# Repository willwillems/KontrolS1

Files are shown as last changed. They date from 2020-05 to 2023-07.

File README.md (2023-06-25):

S1 Project

The following info is all about the S4 MK1, the MK2 has a different (non-panelized) PCB design and thus doesn't allow for reusing the original PCB's without serious modifications. The MK3 also has a single PCB for the mixer and deck sections.

## Setup
- Use the `Kontrol_S1_LC_OLED` sketch
- Either `#include "unit_d.h"` or `#include "unit_c.h"` based on the unit
- Uncomment `#define SCREEN` if using the OLED module
- Edit the `MIDI_NAME` in the `name.c` file to the desired name (these cannot conflict with other S1 units you're using)
- Flash the firmware

## Led off states
All leds are controlled by a transistor activated by the 595 chip. However not all are connected the same way, sending 6 all-off byte packages (`0b00000000`) will turn some of the LED's on, these specific bits to be set to HIGH instead of LOW in order to be turned off.

```
// LED OFF STATES from least significant bit (so notation is in reverse)
// -- BYTE [0]: 0b01010101 --
// CUE1 green - CUE1 blue - CUE2 green - CUE2 blue - CUE3 green - CUE3 blue - CUE4 green - CUE4 blue 
// -- BYTE [1]: 0b00000000 --
// Sample 1 - Sample 2 - Sample 3 - Sample 4 - SYNC - CUE - PLAY - SHIFT
// -- BYTE [2]: 0b11000000 --
// ON AIR - SAMPLES - DECK A/B - DECK C/D - KEYLOCK - MASTER - TEMPO OFFSET UP - TEMPO OFFSET DOWN
// -- BYTE [3]: 0b00000000 --
// LOOP IN - LOOP OUT - TOGGLE DECK C/D - LOAD - NONE - NONE - NONE -NONE
// -- BYTE [4]: 0b11111111 -- LEFT DIGIT
// UP-MIDDLE - UP-RIGHT - DOT - UP-LEFT - DOWN-LEFT - DOWN-MIDDLE - MIDDLE-MIDDLE - DOWN-RIGHT
// -- BYTE [5]: 0b11111111 -- RIGHT DIGIT
// DM - DL - UL - UM - UR - DR - MM - DOT
```

## Button off states
The first four bits of the last packet are connected to GND trough some 330 R resistors. 

```
// BUTTON OFF STATES
// -- BYTE [0]: 0B00000000 --
// PLAY - CP4 - CUE - CP3 - SYNC - CP2 - SHIFT - CP1
// -- BYTE [1]: 0B00000000 --
// S4 - LOAD - S3 - LOOP OUT - S2 - LOOP IN - DECK C/D
// -- BYTE [2]: 0B00001100 --
// X - X - X - X - ENC-R BUT - ENC-L BUT - OFFSET DOWN - OFFSET UP
```

## Pinout
This is the pinout for the DECK A board the DECK B connector is almost identical (but mirrored). The two exceptions are pin 2 and 13, ~~I have no idea what pin 2 is~~ pin 2 is the 165's DS on the DECK B unit. Click [here](https://i.imgur.com/EdCKgI3.jpg) for the DECK B section.

> WARNING: Pinout changed, check below.

pinout
```
// 595’s output enable is connected to GND.
// 165’s CE (chip enable) is connected to GND.
// (13, 14, 15), (16, 17) and (18, 19) are connected together.

1. Q7 (serial out 165)
2. GND (DS from 165's on DECK B)
3. PL (latch pin 165)
4. CP (clock input 165)
5. ENC4-R (330 R)
6. ENC5-L (330 R)
7. ENC4-R (330 R)
8. ENC5-L (330 R)
9. Q7S (serial out 595) (for DECK B this is the serial out of the 4 upper 595's)
10. DS (serial in 595) (for DECK B this is the serial in of the 2 lower 595's)

11. ST_CP (latch pin 595)
12. SH_CP (clock input 595)
13. GND (For DECK B this is the serial in for the 4 upper 595's)
14. GND
15. GND
16. LED V1 (5v but can just be 3.v)
17. LED V1 (5v but can just be 3.v)
18. LED V2 (3.3v)
19. LED V2 (3.3v)
20. VCC

1. GND
2. VCC
3. POT
4. GND
```

## Chip connections

### 74HC595

There are 6 595 chips chained together (the serial out(`Q7S`) for the last 595 is exposed as pin 9 on the connector).

- `ST_CP` and `SH_CP` of every chip are connected to connector pin 11 and 12.
- `MR` is connected to `VCC` on every chip.
- Output enable (`OE`) is connected to `GND` on every chip.

### 74HC165

There are 3 165 chips chained together.

- Clock enable(`CE`) is connect to `GND` on every chip.
- `PL` and `CP` of every chip are connected to connector pin 3 and 4.

## Jog wheels

The rotation of the jogs is measured by two photo-interrupters ([KTIR0611S](http://www.farnell.com/datasheets/2307823.pdf)). The "push down" of the jog is measured by a photo sensor that gets blocked when you push the platter down on it.

### Connections
The 6 pin JST connector is connected to the circuit with the two photo-interrupters. There is also a connection to a third photo-interrupter but they did not end up mounting and integrating this third one into the final product.
```
1. VCC (3.3v)
2. VCC (3.3v) (this "enables" the optical readings?) 
3. GND
4. ENC R
5. ENC L
6. ENC M (not connected or mounted)
```
The 3 color push cable coming out of the jog:
```
BLUE. GND
RED. VCC (3.3V)
WHITE. SIGNAL (analog read: 800~900 off, 1023 on)
-. DUMMY (unused pin on 4-pin JST connector) 
```
> ## Warning
> The jog press is not yet working so the info about it is possibly wrong. The MK1 does seem to use a IR proximity sensor (probably the [HSDL-9100-024](https://docs.broadcom.com/doc/AV02-2259EN) but so far no reliable readings have been produced. The MK2 uses an Ambient Light Sensor with an I2C Interface called the [VNCL4000](https://cdn-shop.adafruit.com/datasheets/vcnl4000.pdf). The current MK1 problems might just be calibration issues but could also be something more serious.

## Observations
- VCC should be 3.3v, not 5v. The 595 works with 5v and you will not fry the LED's but the 165 will not work and you might damage it.
- You can easily run the 165 and 595 chips with hardware SPI.
- The left and right circuit board are not identical at all though the connectors appear to be.

## Custom FX PCB

The custom FX PCB has the same layout on both sides so only one version is required (it has both the L&R mounting holes). The custom FX PCB provides a 165 and 595 interface for the buttons and LED's respectively and a separate connector for the potentiometer signals.

### Pinout

```
1. INH (165-15) [Clock enable]
2. SER (165-10) [Serial data input]
3. QH (595-9) [Serial data output]
4. LATCH 165 (165-1) [Parallel load input]
5. RCK (595-12) [storage register clock input]
6. QH (165-9) [Serial out]
7. SER (595-14)[Serial data input]
8. CLOCK
9. GND
10. VCC

11. VCC
12. GND
13. FX_3
14. FX_2
15. FX_1
16. FX_DW
```

## Parts

These simplified BOM's are for the MK4 releases of the brain and pot boards.

### Brain board

These are the parts needed to populate 1 brain board, to convert one S4 to two S1 units you'd need these parts x2.

| Part | Amount | Value |
| --- | --- | ----- |
| Molex Picoblade (1.25mm) 10-pin | 3 | |
| Molex Picoblade (1.25mm) 8-pin | 1 | |
| Molex Picoblade (1.25mm) 6-pin | 3 | |
| Molex Picoblade (1.25mm) 4-pin | 2 | |
| M3 metal standoffs | 4 | 15mm  |
| M3 metal screws | 8 | 6mm |
| USB-B socket | 1 | |
| Teensy LC | 1 | |
| Capacitor US 1206 | 1 | 100nF |
| Resistor US 1206 (0805 compatible) | 1 | 1M |

The 1M resistor might need a higher value.

### Pot board

These are the parts needed to populate 1 brain board, to convert one S4 to two S1 units you'd need these parts x2. The standoffs needed are already included with the brain BOM.

| Part | Amount | Value |
| --- | --- | ----- |
| Molex Picoblade (1.25mm) 10-pin | 1 | |
| Molex Picoblade (1.25mm) 6-pin | 1 | |
| Resistor US 0805 | 5 | 82 |
| Resistor US 0805 | 8 | 10K |
| 74HC595D | 1 | |
| 74HC165D | 1 | |
| Capacitor US 1206 | 6 | 100nF |

The four capacitors for the potentiometers might need a lower value.

## Custom OLED PCB

Contains adapter from 1.25mm JST to OLED, a step-up to 12V and some passive components the OLED driver needs.

### Pinout

```
1. GND
2. CLOCK
3. GND
4. MOSI
5. SS-SCREEN
6. VCC
7. DC
8. RST
```

# Screen

The screen uses https://github.com/ErikMinekus/traktor-api-client to get data from traktor + a local server to send it to the teensy over serial.

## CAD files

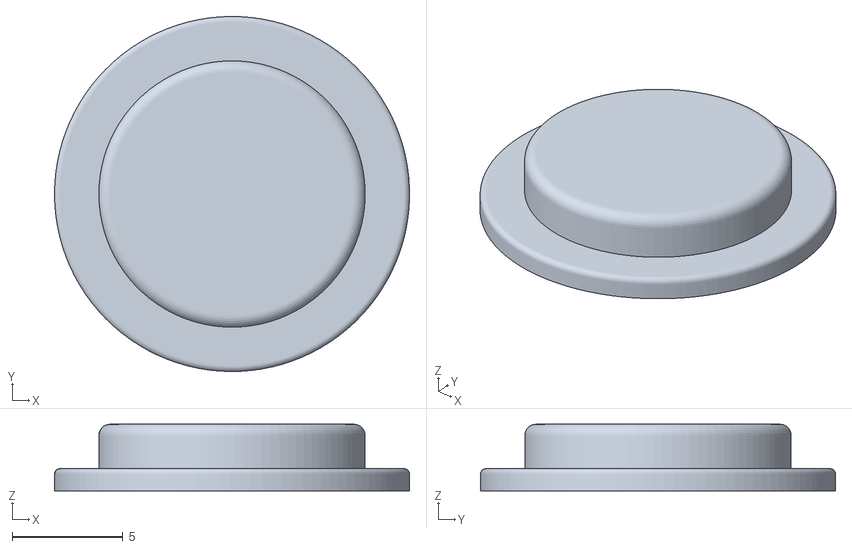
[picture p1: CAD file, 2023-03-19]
3D/s4 front plug.stl
16.0 x 16.0 x 3.00

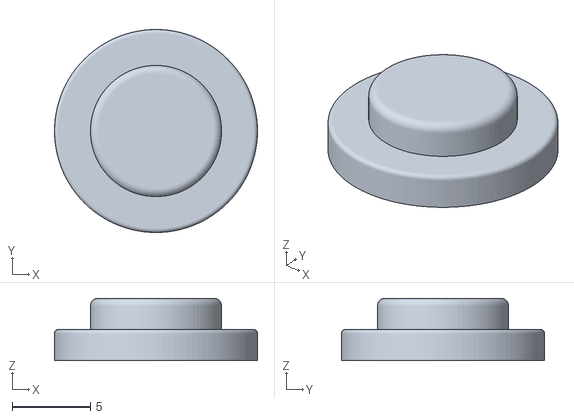
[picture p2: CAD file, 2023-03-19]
3D/s4plugback84-130.stl
13.0 x 13.0 x 4.00

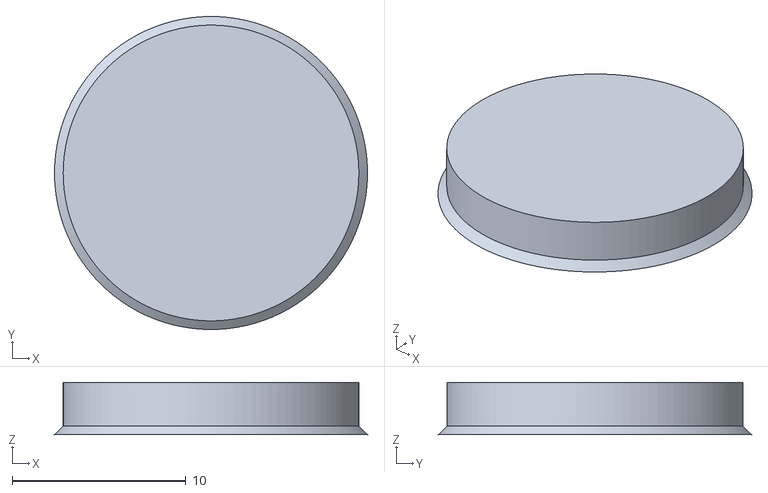
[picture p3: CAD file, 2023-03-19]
3D/midiplug.stl
18.0 x 18.0 x 3.00

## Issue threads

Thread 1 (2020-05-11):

Fader readings have "inertia"

NickolasBoyer, 2020-05-11:
This is when moving the fader up and down quickly:

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

Lower levels are not even reached when moving quickly so it's not simply a delay, feels like a weirdly placed capacitor.

NickolasBoyer, 2020-05-12:
Fixed in 97d0fda pinout was wrong

Closed 2020-05-12.

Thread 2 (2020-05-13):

74HC165 just outputs D7 state on Q7 (all chips)

NickolasBoyer, 2020-05-13:
I might just have fried these chips but not sure about this at all.

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

It does seem like the Q7 only goes high when the latch pin goes low but it subsequently stays high for many SPI cycles until D7 goes low again.

NickolasBoyer, 2020-05-13:
Fixed by 24492eb

Closed 2020-05-13.

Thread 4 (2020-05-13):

Some MIDI note's are inverted

NickolasBoyer, 2020-05-13:
Such as the hotcue buttons, they send a note off on press and a note on on release.

NickolasBoyer, 2020-06-18:
fd906aaf19159a711b77e02d6acf16d90195b7c5 fixes this, typo in default button state, was reading default led state instead of default button state.

Closed 2020-06-18.

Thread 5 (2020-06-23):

Jog touch module does not work yet

NickolasBoyer, 2020-06-23:
Semi-readable values are spitted out by an `analogRead` call but very inconsistently and is influenced by touching the connectors. Mostly `analogRead` just returns: 1023.

NickolasBoyer, 2020-07-02:
From online pictures the proximity sensor seems to be a HSDL-9100. So far some possibel solutions seem to be:

- Using a higher voltage (unlikely)
- Using a pull-down or pull-up resistor with a high value (10K or 100K)

```
----------------------------------------------------

           PhotoR     10K
 +5    o---/\/\/--.--/\/\/---o GND
                  |
 Pin 0 o-----------

----------------------------------------------------
```

NickolasBoyer, 2020-07-11:
This was fixed by using a pull-down resistor, 10K seems to much though.

Closed 2020-07-11.

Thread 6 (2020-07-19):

Add resistors and caps to pots

NickolasBoyer, 2020-07-19:
Like the design of the original S4 PCB, capacitors might stablize potentiometer readigs although  https://github.com/dxinteractive/ResponsiveAnalogRead might already do the job fine.

NickolasBoyer, 2020-11-25:
fixed in 8bfa246

capacitor are optional, resistor was not added

Closed 2020-11-25.

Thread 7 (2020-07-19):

Add smaller current limiting resistors to LED's

NickolasBoyer, 2020-07-19:
Currently the pot board LED's are very dim

NickolasBoyer, 2020-10-20:
Should be fixed in cbd8d652e8d3ef9692d65b48acaec7065aae5a57

Closed 2020-10-20.

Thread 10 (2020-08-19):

Connect both CE's on FX PCB MK3

NickolasBoyer, 2020-08-19:
Currently, only the 165's CE is connected to pin 1 of the FX board. Make it fully SPI compatible (enabling SS) by connecting both the 595's and the 165's.

NickolasBoyer, 2020-09-22:
Not fixed but integrated an alternative using a transistor in fd14755c9442d2429f3247b3a386ff9f93cfd797

Closed 2020-09-22.

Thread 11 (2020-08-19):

Fix dimensions FX MK3 board

NickolasBoyer, 2020-08-19:
The FX board dimensions work but are not perfect, finetune them for the MK3.

NickolasBoyer, 2020-09-22:
Fixed in fd14755c9442d2429f3247b3a386ff9f93cfd797

Closed 2020-09-22.

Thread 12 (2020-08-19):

Add screwholes to FX MK3 board to mount Brain MK2

NickolasBoyer, 2020-08-19:

NickolasBoyer, 2020-09-22:
Fixed in fd14755c9442d2429f3247b3a386ff9f93cfd797

Closed 2020-09-22.

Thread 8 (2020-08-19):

Design custom OLED board

NickolasBoyer, 2020-08-19:
For the SH1122 driven 256 x 64 2.08 inch OLED display.

## Wiring

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

## Docs

- [SH1122](https://www.buydisplay.com/download/ic/SH1122.pdf)
- [Screen module](https://www.buydisplay.com/download/manual/ER-OLED0208-1_Datasheet.pdf)

NickolasBoyer, 2020-09-03:
Position should be either under the display itself but with a relatively small PCB or tucked against the jog, cannot mount on jog screws, that sections protrudes the PCB.

NickolasBoyer, 2020-10-04:
Deigned a small test board in 640ccb3

NickolasBoyer, 2020-11-28:
OLED board is working perfectly

Closed 2020-11-28.

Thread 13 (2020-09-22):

Mounting holes for PCB stacking do not line up

NickolasBoyer, 2020-09-22:

NickolasBoyer, 2020-10-17:
Also bottom silk is mirrored on brain

NickolasBoyer, 2020-10-20:
Both should be fixed in cbd8d652e8d3ef9692d65b48acaec7065aae5a57

Closed 2020-10-20.

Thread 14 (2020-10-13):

Design mixer brain

NickolasBoyer, 2020-10-13:
The mixer section could also be converted to a stand-alone unit.

It uses [ADS7844](https://www.ti.com/product/ADS7844) chips to ADC the pots/faders and sends the values to the CPU over SPI. [Here](https://github.com/vladkosarev/Arduino.ADS7841/blob/master/ADS7841.ino) is an example Arduino sketch.

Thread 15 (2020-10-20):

Convert Brain and Pot board designs to KiCAD

NickolasBoyer, 2020-10-20:
Both (including the custom library) should be converted to KiCAD. One of the board has issues with wierd tracks (inconsistent track width and wire stubs) due to a previous conversion. This too should be fixed. Library can be moved to it's own GH repo and just be used with existing KiCAD symbols.

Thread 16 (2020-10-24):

LED's don't work on deck C

NickolasBoyer, 2020-10-24:
Depends on the code uploaded but seems almost random.

NickolasBoyer, 2020-10-24:
Getting LED's to respond seems to work reliably by adding a 200 ms delay after pulling the latch pin low. They do not work correctly yet though.

NickolasBoyer, 2020-11-25:
fixed in most recent sketches

NickolasBoyer, 2020-11-28:
fixed in 1302d9a

Closed 2020-11-28.

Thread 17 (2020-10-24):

FX board needs capacitor on jog press read

NickolasBoyer, 2020-10-24:
In order to stabilize the incoming analog readings from the IR sensor.

NickolasBoyer, 2020-11-25:
Fixed in 8bfa246

Closed 2020-11-25.

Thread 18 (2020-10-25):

Debounce inputs

NickolasBoyer, 2020-10-25:
Either through hardware or software, something like https://github.com/dxinteractive/ResponsiveAnalogRead might work for the potentiometers, a better scaling algo would also solve this.

NickolasBoyer, 2020-11-28:
possibly fixed in 1302d9a, new boards might eliminate analog noise as well, else we'll implement software debouncing

Closed 2020-11-28.

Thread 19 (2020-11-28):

Encoder buttons on C are inverted

NickolasBoyer, 2020-11-28:

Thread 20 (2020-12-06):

Port pins silkscreen is on wrong side board

NickolasBoyer, 2020-12-06:
Should be on the bottom, is on top.

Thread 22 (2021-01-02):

PCB error

4dvn, 2021-01-02:
Hello,
the zip files of POT_BOARD_MK3.zip & S1-BRAIN-MK2.zip error you need to check and remove it ^^

NickolasBoyer, 2021-01-02:
Thanks for opening the issue! Could you be a bit more specific? I don't recommend manufacturing anything else than the MK4 PCB's btw.

Closed 2023-03-19.

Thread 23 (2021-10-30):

Newer models have different LED wiring

willwillems, 2021-10-30:
Requiring a different ledmap, difference in the C unit seems major, D unit minor.

willwillems, 2022-10-16:
https://github.com/willwillems/KontrolS1/pull/24

Closed 2023-03-19.

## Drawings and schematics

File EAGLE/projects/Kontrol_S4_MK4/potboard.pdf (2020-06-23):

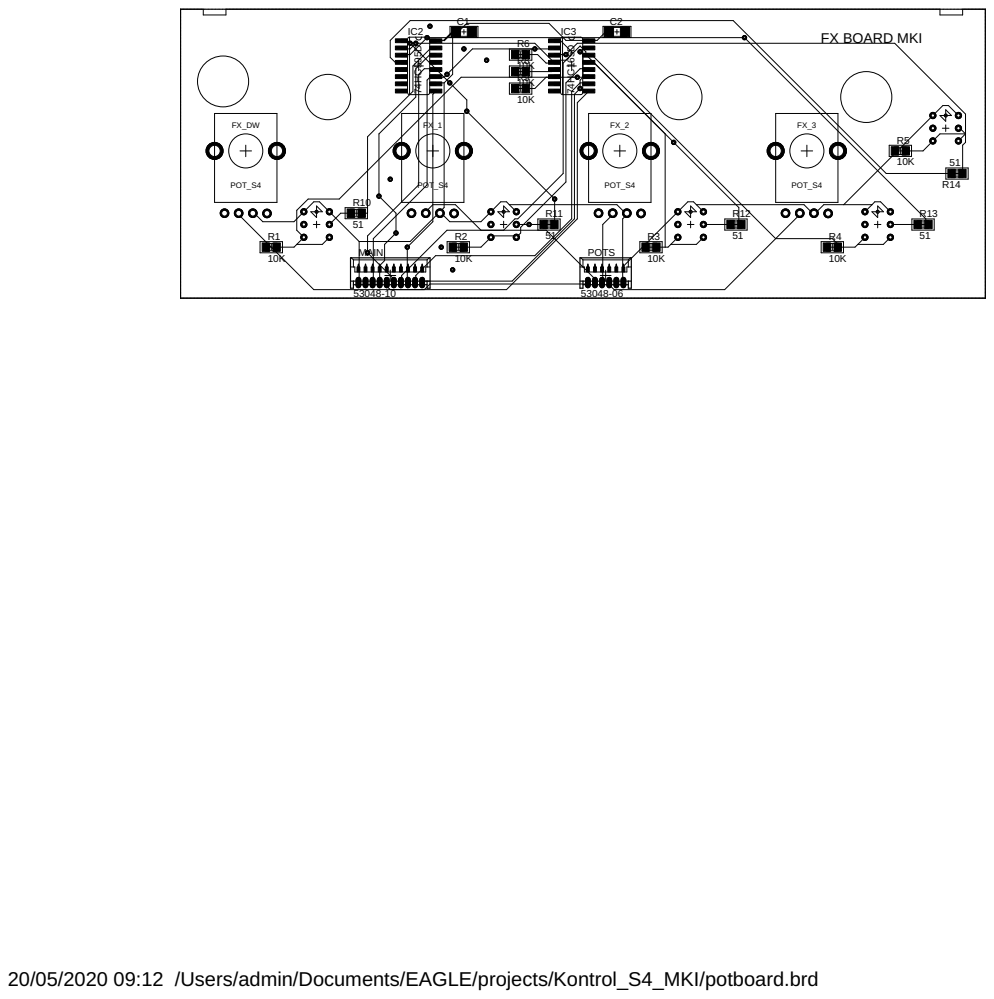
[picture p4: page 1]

20/05/2020 09:12 /Users/admin/Documents/EAGLE/projects/Kontrol_S4_MKI/potboard.brd

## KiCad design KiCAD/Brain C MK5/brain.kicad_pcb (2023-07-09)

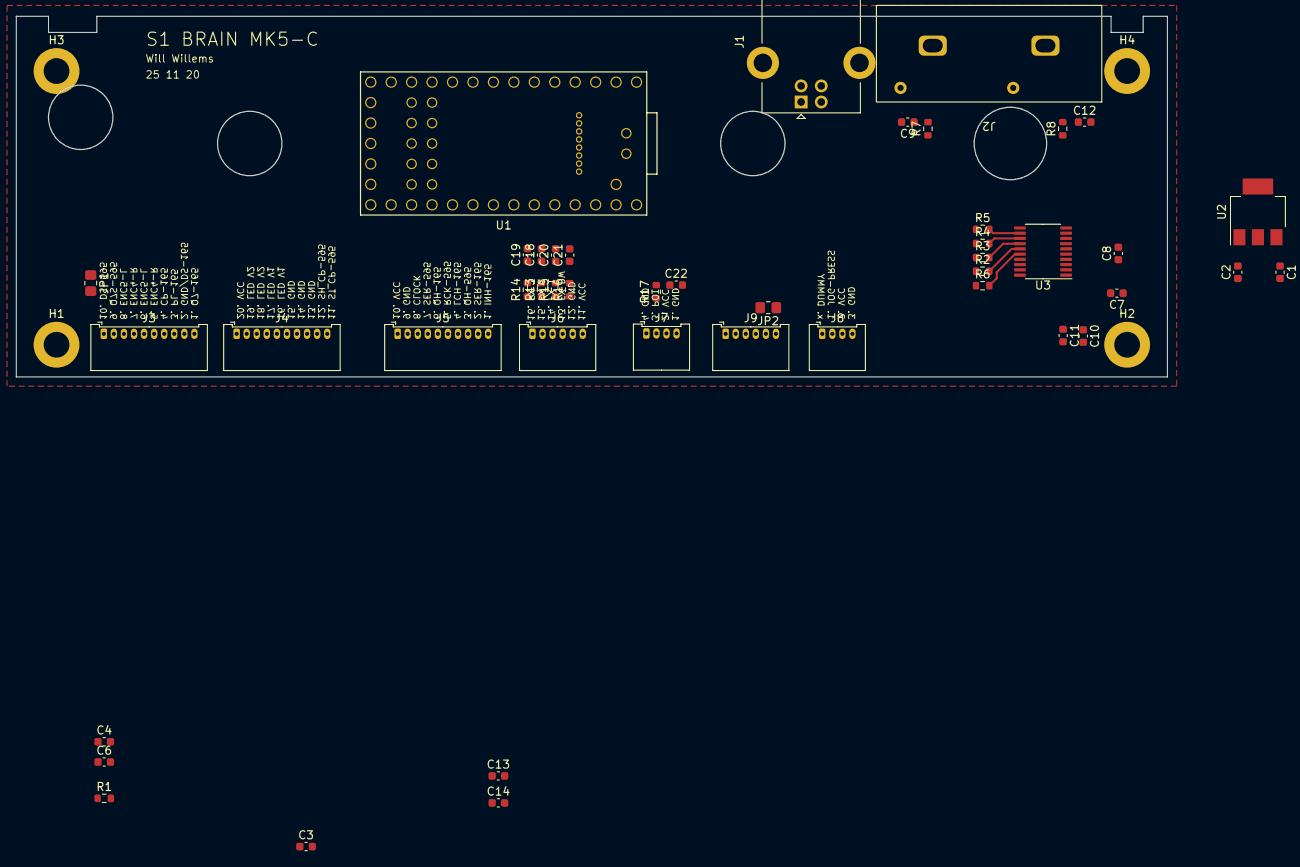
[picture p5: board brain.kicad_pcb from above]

Board: 4 copper layers, 143.0 x 44.8 mm, 49 parts (0 on the bottom side), 49 nets.

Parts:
C1, C3, C4, C6, C10: 100nF; C_0603_1608Metric
C2, C11: 10uF; C_0603_1608Metric
C7, C8: 2.2uF; C_0603_1608Metric
C9, C12: 2.2nF; C_0603_1608Metric
C13, C14: C_Small; C_0603_1608Metric
C18, C19, C20, C21, C22: 1.2uF; C_0603_1608Metric
H1, H2, H3, H4: MountingHole_Pad; MountingHole_3.2mm_M3_ISO7380_Pad
J1: USB_B; USB_B_Lumberg_2411_02_Horizontal
J2: Conn_Coaxial_x2_Isolated; RCA_double
J3, J4, J5: Conn_01x10; Molex_PicoBlade_53048-1010_1x10_P1.25mm_Horizontal
J6, J9: Conn_01x06; Molex_PicoBlade_53048-0610_1x06_P1.25mm_Horizontal
J7, J8: Conn_01x04; Molex_PicoBlade_53048-0410_1x04_P1.25mm_Horizontal
JP1, JP2: Jumper_2_Bridged; R_0805_2012Metric_Pad1.20x1.40mm_HandSolder
R1: 10R; R_0603_1608Metric
R2, R3, R4, R5: 22; R_0603_1608Metric
R6: 0; R_0603_1608Metric
R7, R8: 470; R_0603_1608Metric
R13, R14, R15, R16, R17: 2.2K; R_0603_1608Metric
U1: Teensy4.0; Teensy40_SMT
U2: LD1117S33TR_SOT223; SOT-223-3_TabPin2
U3: PCM5102; TSSOP-20_4.4x6.5mm_P0.65mm

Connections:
+3.3V: C4.1, C6.1, U1.16 (3V3), U1.31 (3V3), U3.1 (CPVDD), U3.20 (DVDD)
+3.3VA: C2.1, C10.1, C11.1, U2.2 (VO), U3.8 (AVDD), U3.17 (XSMT)
+5V: C14.1, R1.1
/165-LATCH: J3.8, J5.7, U1.11 (9_OUT1C)
/595-LATCH: J4.10, J5.6, U1.10 (8_TX2_IN1)
/CE-595-165: J3.9, J5.10, U1.12 (10_CS_MQSR)
/CLOCK: J3.7, J4.9, J5.3, U1.20 (13_SCK_CRX1_LED)
/Connectors/165_BRIDGE: J3.10, J5.9
/Connectors/595_BRIDGE: J3.1, J5.8
/Connectors/595_OUT_MAIN: J3.2, JP1.2 (B)
/DAC (PCM5102)/AUDIO_OUT_L: C12.1, R8.2
/DAC (PCM5102)/AUDIO_OUT_R: C9.1, R7.2
/DAC (PCM5102)/LDO: C3.1, U3.18 (LDOO)
/ENCL1: J3.5, U1.4 (2_OUT2)
/ENCL2: J3.6, U1.5 (3_LRCLK2)
/ENCR1: J3.3, U1.6 (4_BCLK2)
/ENCR2: J3.4, U1.7 (5_IN2)
/FADER_1: J7.2, R17.1
/JOG-MOVE1: J9.2, U1.8 (6_OUT1D)
/JOG-MOVE2: J9.3, U1.9 (7_RX2_OUT1A)
/JOG_PRESS_IR: J8.2, U1.21 (14_A0_TX3_SPDIF_OUT)
/MISO: J5.5, U1.14 (12_MISO_MQSL)
/MOSI: J5.4, U1.13 (11_MOSI_CTX1)
/POT_1: J6.1, R14.1
/POT_2: J6.2, R13.1
/POT_3: J6.3, R15.1
/POT_4: J6.4, R16.1
/USB_D+: J1.3 (D+), U1.54 (D+)
/USB_D-: J1.2 (D-), U1.53 (D-)
GND: C1.2, C2.2, C3.2, C4.2, C6.2, C8.2, C9.2, C10.2, C11.2, C12.2, C13.2, C14.2, C18.2, C19.2, C20.2, C21.2, C22.2, H1.1, H2.1, H3.1, H4.1, J1.4 (GND), J1.5 (Shield), J2.2 (Ext1), J2.4 (Ext2), J4.6, J4.7, J4.8, J5.2, J6.5, J7.1, J7.4, J8.4, J9.4, JP1.1 (A), R6.1, U1.1 (GND), U1.17 (GND), U1.32 (GND), U2.1 (GND), U3.3 (CPGND), U3.9 (AGND), U3.10 (DEMP), U3.11 (FLT), U3.19 (DGND)
unnamed: J9.5, JP2.2 (B)
unnamed: C19.1, R14.2, U1.22 (15_A1_RX3_SPDIF_IN)
unnamed: C18.1, R13.2, U1.23 (16_A2_RX4_SCL1)
unnamed: C20.1, R15.2, U1.24 (17_A3_TX4_SDA1)
unnamed: C21.1, R16.2, U1.25 (18_A4_SDA0)
unnamed: C22.1, R17.2, U1.26 (19_A5_SCL0)
unnamed: C1.1, R1.2, U2.3 (VI)
unnamed: R4.2, U3.13 (BCK)
unnamed: C7.2, U3.4 (CAPM)
unnamed: C7.1, U3.2 (CAPP)
unnamed: R3.2, U3.14 (DIN)
unnamed: R6.2, U3.16 (FMT)
unnamed: R2.2, U3.15 (LRCK)
unnamed: R8.1, U3.6 (OUTL)
unnamed: R7.1, U3.7 (OUTR)
unnamed: R5.2, U3.12 (SCK)
unnamed: C8.1, U3.5 (VNEG)
VBUS: C13.1, J1.1 (VBUS), U1.33 (VIN), U1.34 (VUSB)
VCC: J4.1, J4.2, J4.3, J4.4, J4.5, J5.1, J6.6, J7.3, J8.3, J9.6, JP2.1 (A)

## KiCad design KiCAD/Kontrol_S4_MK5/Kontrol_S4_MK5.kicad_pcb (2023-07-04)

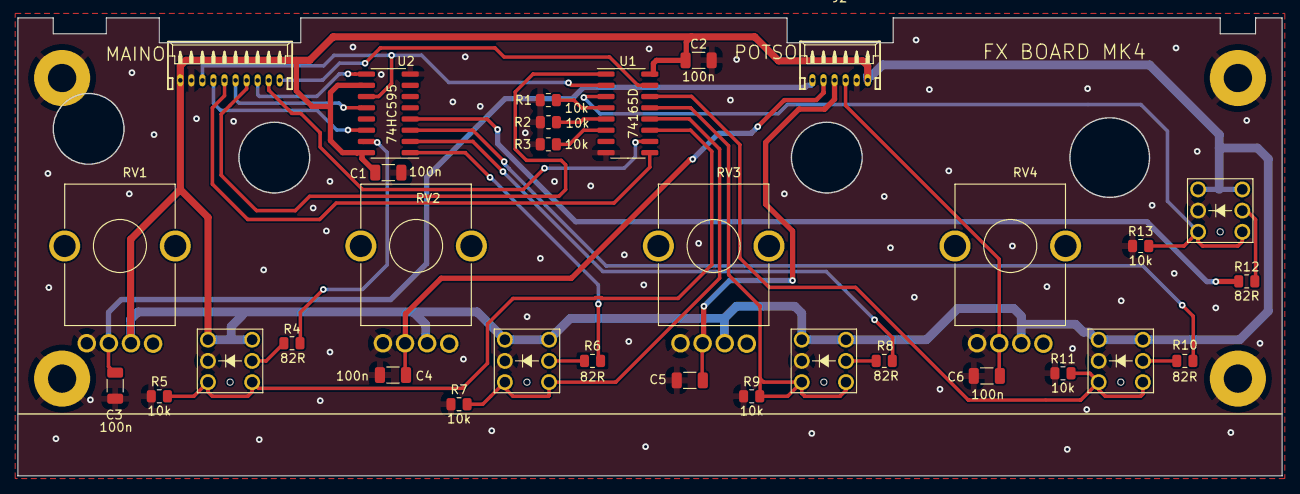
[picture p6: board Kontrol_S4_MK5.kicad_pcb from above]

Board: 2 copper layers, 143.0 x 51.8 mm, 36 parts (0 on the bottom side), 32 nets.

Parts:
C1, C2, C3, C4, C5, C6: 100n; C_1206_3216Metric
H1, H2, H3, H4: STANDOFF_ELECTRICAL; STANDOFF-ELECTRICAL
J1: Conn_01x10; CON_MAINO
J2: Conn_01x06; CON_POTSO
R1, R2, R3, R5, R7, R9, R11, R13: 10k; R_0805_2012Metric
R4, R6, R8, R10, R12: 82R; R_0805_2012Metric
RV1: FX_DWO; Potentiometer_custom
RV2: FX_1; Potentiometer_custom
RV3: FX_2; Potentiometer_custom
RV4: FX_3; Potentiometer_custom
SW1, SW2, SW3, SW4, SW5: Button; BUTTON
U1: 74165D; SOIC-16_3.9x9.9mm_P1.27mm
U2: 74HC595; SOIC-16_3.9x9.9mm_P1.27mm

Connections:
/165_IN: J1.2, U1.10 (SER)
/595_OUT: J1.3, U2.9 (QH')
/A1: C3.1, J2.6, RV1.2
/A2: C4.1, J2.5, RV2.2
/A3: C5.1, J2.4, RV3.2
/A4: C6.1, J2.3, RV4.2
/CE_165: J1.1, U1.15 (CLK_INH)
/CLOCK: J1.8, U1.2 (CLK), U2.11 (SRCLK)
/D1: R5.2, SW1.1, U1.11 (A)
/D2: R7.2, SW2.1, U1.12 (B)
/D3: R9.2, SW3.1, U1.13 (C)
/D4: R11.2, SW4.1, U1.14 (D)
/D5: R13.2, SW5.1, U1.3 (E)
/D6: R1.2, U1.4 (F)
/D7: R2.2, U1.5 (G)
/D8: R3.2, U1.6 (H)
/LATCH_165: J1.4, U1.1 (SH/LD)
/LATCH_595: J1.5, U2.12 (RCLK)
/MISO: J1.6, U1.9 (QH)
/MOSI: J1.7, U2.14 (SER)
GND: C1.2, C2.2, C3.2, C4.2, C5.2, C6.2, H1.P1, H2.P1, H3.P1, H4.P1, J1.9, J2.2, R1.1, R2.1, R3.1, R5.1, R7.1, R9.1, R11.1, R13.1, RV1.3, RV2.3, RV3.3, RV4.3, SW1.LED-, SW2.LED-, SW3.LED-, SW4.LED-, SW5.LED-, U1.8 (GND), U2.8 (GND)
unnamed: R4.1, U2.15 (QA)
unnamed: R4.2, SW1.LED+
unnamed: R6.1, U2.1 (QB)
unnamed: R6.2, SW2.LED+
unnamed: R8.1, U2.2 (QC)
unnamed: R8.2, SW3.LED+
unnamed: R10.1, U2.3 (QD)
unnamed: R10.2, SW4.LED+
unnamed: R12.1, U2.4 (QE)
unnamed: R12.2, SW5.LED+
VCC: C1.1, C2.1, J1.10, J2.1, RV1.1, RV2.1, RV3.1, RV4.1, SW1.2, SW2.2, SW3.2, SW4.2, SW5.2, U1.16 (VCC), U2.10 (~SRCLR), U2.16 (VCC)

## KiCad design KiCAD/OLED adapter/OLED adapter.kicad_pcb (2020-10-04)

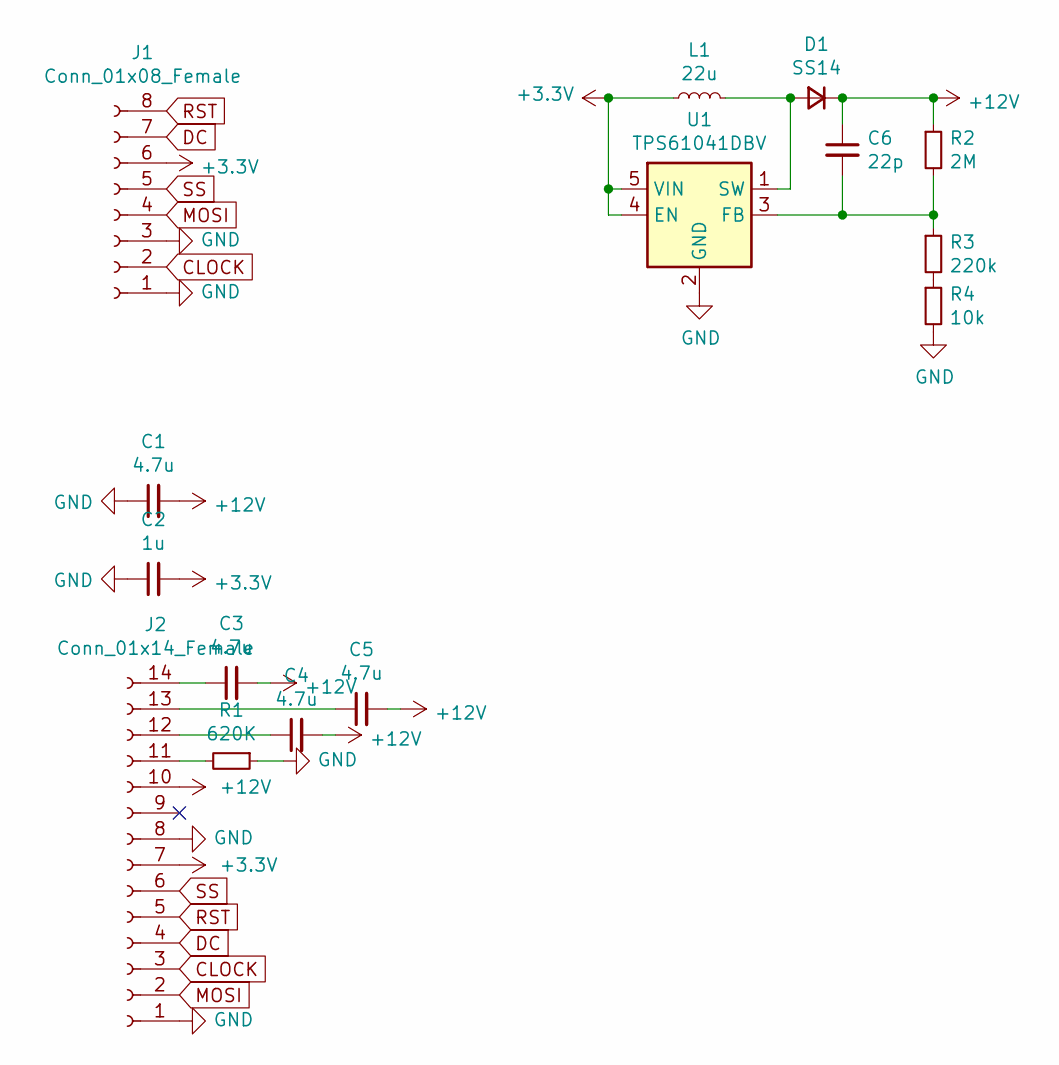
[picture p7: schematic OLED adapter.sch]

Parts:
C1, C3, C4, C5: 4.7u; C_0603_1608Metric_Pad1.05x0.95mm_HandSolder
C2: 1u; C_0603_1608Metric_Pad1.05x0.95mm_HandSolder
C6: 22p; C_0603_1608Metric_Pad1.05x0.95mm_HandSolder
D1: SS14; D_SMA_Handsoldering
J1: Conn_01x08_Female; Hirose_DF13-08P-1.25DS_1x08_P1.25mm_Horizontal
J2: Conn_01x14_Female; TE_1-1734839-4_1x14-1MP_P0.5mm_Horizontal
L1: 22u; L_0805_2012Metric_Pad1.15x1.40mm_HandSolder
R1: 620K; R_0603_1608Metric_Pad1.05x0.95mm_HandSolder
R2: 2M; R_0603_1608Metric_Pad1.05x0.95mm_HandSolder
R3: 220k; R_0603_1608Metric_Pad1.05x0.95mm_HandSolder
R4: 10k; R_0603_1608Metric_Pad1.05x0.95mm_HandSolder
U1: TPS61041DBV; SOT-23-5_HandSoldering

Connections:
+3V3: C2.2, J1.6, J2.7, L1.1, U1.4 (EN), U1.5 (VIN)
+12V: C1.2, C3.2, C4.2, C5.2, C6.1, D1.1 (K), J2.10, R2.1
CLOCK: J1.2, J2.3
DC: J1.7, J2.4
GND: C1.1, C2.1, J1.1, J1.3, J2.1, J2.8, R1.1, R4.2, U1.2 (GND)
MOSI: J1.4, J2.2
unnamed: C3.1, J2.14
unnamed: C4.1, J2.12
unnamed: C5.1, J2.13
unnamed: C6.2, R2.2, R3.1, U1.3 (FB)
unnamed: D1.2 (A), L1.2, U1.1 (SW)
unnamed: J2.11, R1.2
unnamed: R3.2, R4.1
RST: J1.8, J2.5
SS: J1.5, J2.6

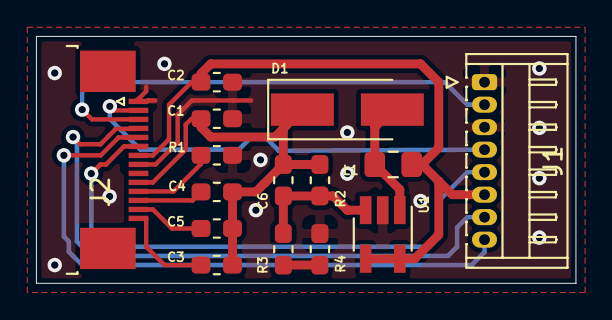
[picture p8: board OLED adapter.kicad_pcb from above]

Board: 2 copper layers, 30.0 x 13.7 mm, 15 parts (0 on the bottom side), 15 nets.

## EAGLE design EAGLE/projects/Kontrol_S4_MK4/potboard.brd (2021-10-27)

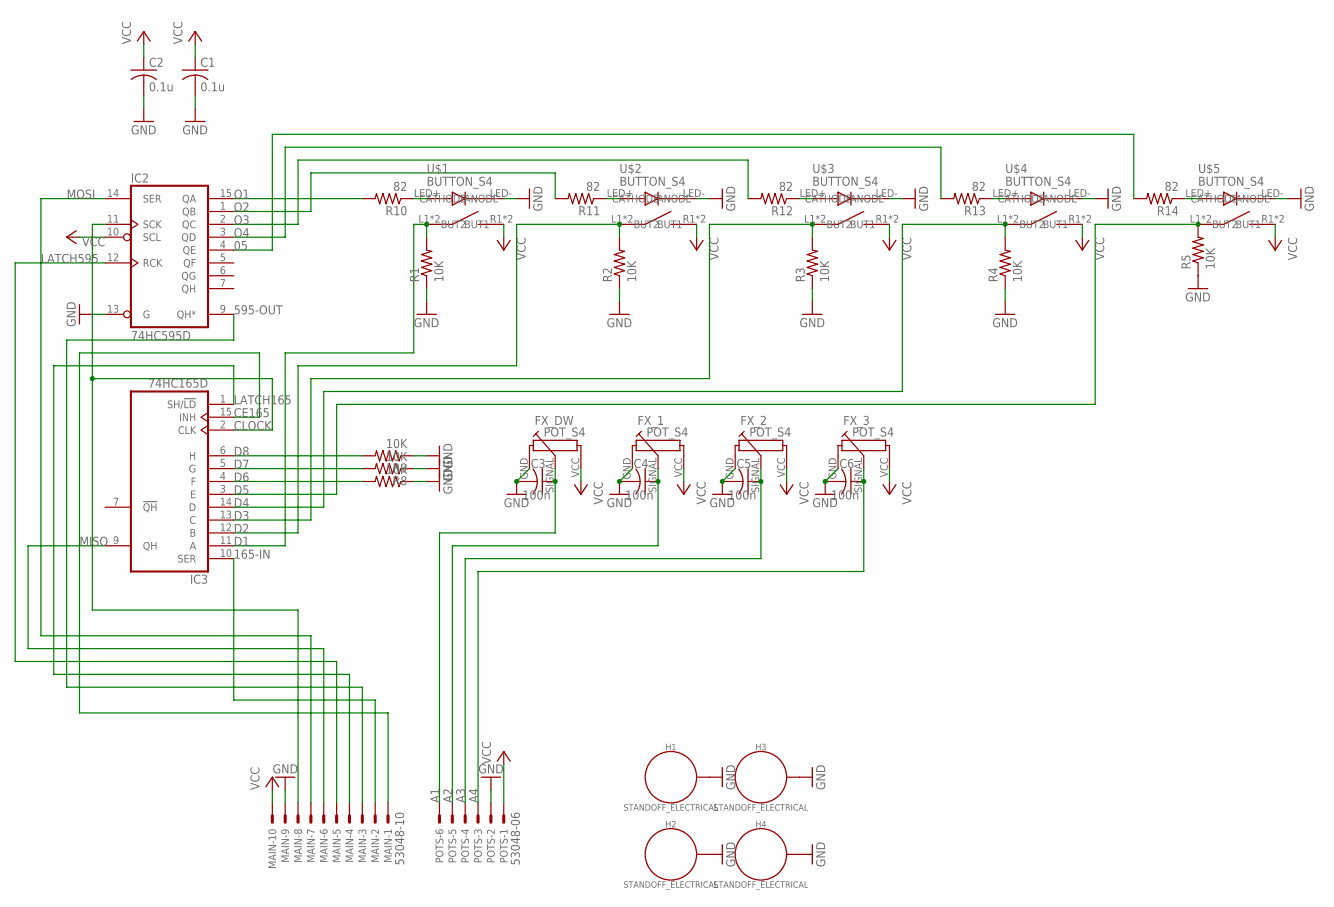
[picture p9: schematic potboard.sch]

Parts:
C1, C2: 0.1u; C1206
C3, C4, C5, C6: 100n; C1206
FX_1, FX_2, FX_3: POT_S4
FX_DW: POT_S4
H1, H2, H3, H4: STANDOFF_ELECTRICAL; STANDOFF-ELECTRICAL
IC2: 74HC595D; SO16
IC3: 74HC165D; SO16
MAIN: 53048-10
POTS: 53048-06
R1, R2, R3, R4, R5, R6, R8, R9: 10K; R0805
R10, R11, R12, R13, R14: 82; R0805
U$1, U$2, U$3, U$4, U$5: BUTTON_S4

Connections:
05: IC2.4 (QE), R14.2
165-IN: IC3.10 (SER), MAIN.2
595-OUT: IC2.9 (QH*), MAIN.3
A1: C3.1, FX_DW.SIGNAL (1S), POTS.6
A2: C4.1, FX_1.SIGNAL (1S), POTS.5
A3: C5.1, FX_2.SIGNAL (1S), POTS.4
A4: C6.1, FX_3.SIGNAL (1S), POTS.3
CE165: IC3.15 (INH), MAIN.1
CLOCK: IC2.11 (SCK), IC3.2 (CLK), MAIN.8
D1: IC3.11 (A), R1.2, U$1.L1 (BUT1), U$1.L2 (BUT1)
D2: IC3.12 (B), R2.2, U$2.L1 (BUT1), U$2.L2 (BUT1)
D3: IC3.13 (C), R3.2, U$3.L1 (BUT1), U$3.L2 (BUT1)
D4: IC3.14 (D), R4.2, U$4.L1 (BUT1), U$4.L2 (BUT1)
D5: IC3.3 (E), R5.2, U$5.L1 (BUT1), U$5.L2 (BUT1)
D6: IC3.4 (F), R6.2
D7: IC3.5 (G), R8.2
D8: IC3.6 (H), R9.2
GND: C1.2, C2.2, C3.2, C4.2, C5.2, C6.2, FX_1.GND (1A), FX_2.GND (1A), FX_3.GND (1A), FX_DW.GND (1A), H1.P1, H2.P1, H3.P1, H4.P1, IC2.8 (GND), IC2.13 (G), IC3.8 (GND), MAIN.9, POTS.2, R1.1, R2.1, R3.1, R4.1, R5.1, R6.1, R8.1, R9.1, U$1.LED- (CATHODE), U$2.LED- (CATHODE), U$3.LED- (CATHODE), U$4.LED- (CATHODE), U$5.LED- (CATHODE)
LATCH165: IC3.1 (SH/!LD), MAIN.4
LATCH595: IC2.12 (RCK), MAIN.5
MISO: IC3.9 (QH), MAIN.6
MOSI: IC2.14 (SER), MAIN.7
unnamed: R10.1, U$1.LED+ (ANODE)
unnamed: R11.1, U$2.LED+ (ANODE)
unnamed: R12.1, U$3.LED+ (ANODE)
unnamed: R13.1, U$4.LED+ (ANODE)
unnamed: R14.1, U$5.LED+ (ANODE)
O1: IC2.15 (QA), R10.2
O2: IC2.1 (QB), R11.2
O3: IC2.2 (QC), R12.2
O4: IC2.3 (QD), R13.2
VCC: C1.1, C2.1, FX_1.VCC (1E), FX_2.VCC (1E), FX_3.VCC (1E), FX_DW.VCC (1E), IC2.10 (SCL), IC2.16 (VCC), IC3.16 (VCC), MAIN.10, POTS.1, U$1.R1 (BUT2), U$1.R2 (BUT2), U$2.R1 (BUT2), U$2.R2 (BUT2), U$3.R1 (BUT2), U$3.R2 (BUT2), U$4.R1 (BUT2), U$4.R2 (BUT2), U$5.R1 (BUT2), U$5.R2 (BUT2)

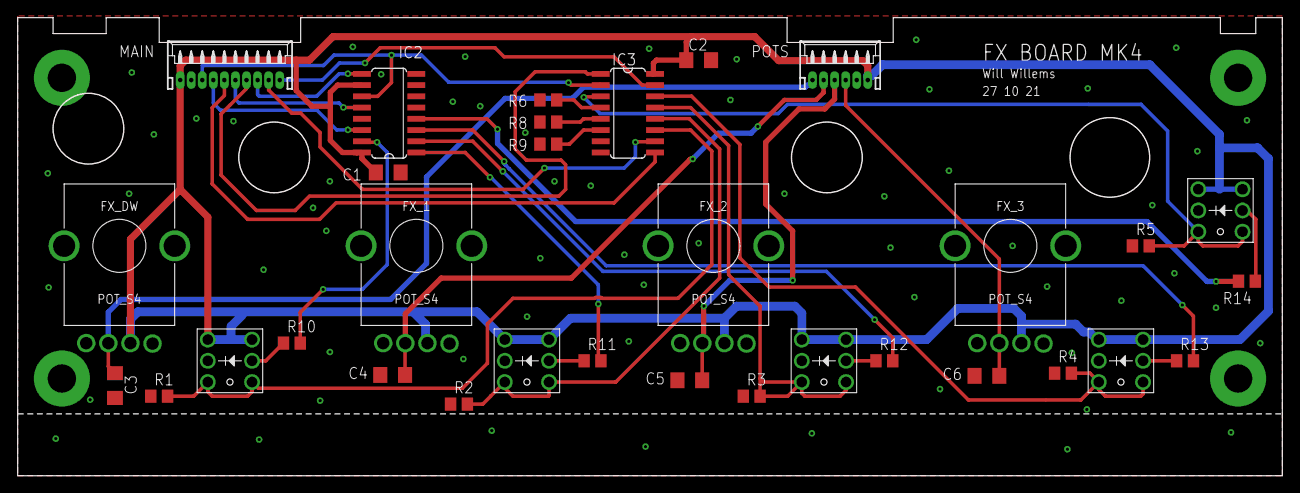
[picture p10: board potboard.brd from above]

Board: 2 copper layers, 143.0 x 51.8 mm, 36 parts (0 on the bottom side), 32 nets.

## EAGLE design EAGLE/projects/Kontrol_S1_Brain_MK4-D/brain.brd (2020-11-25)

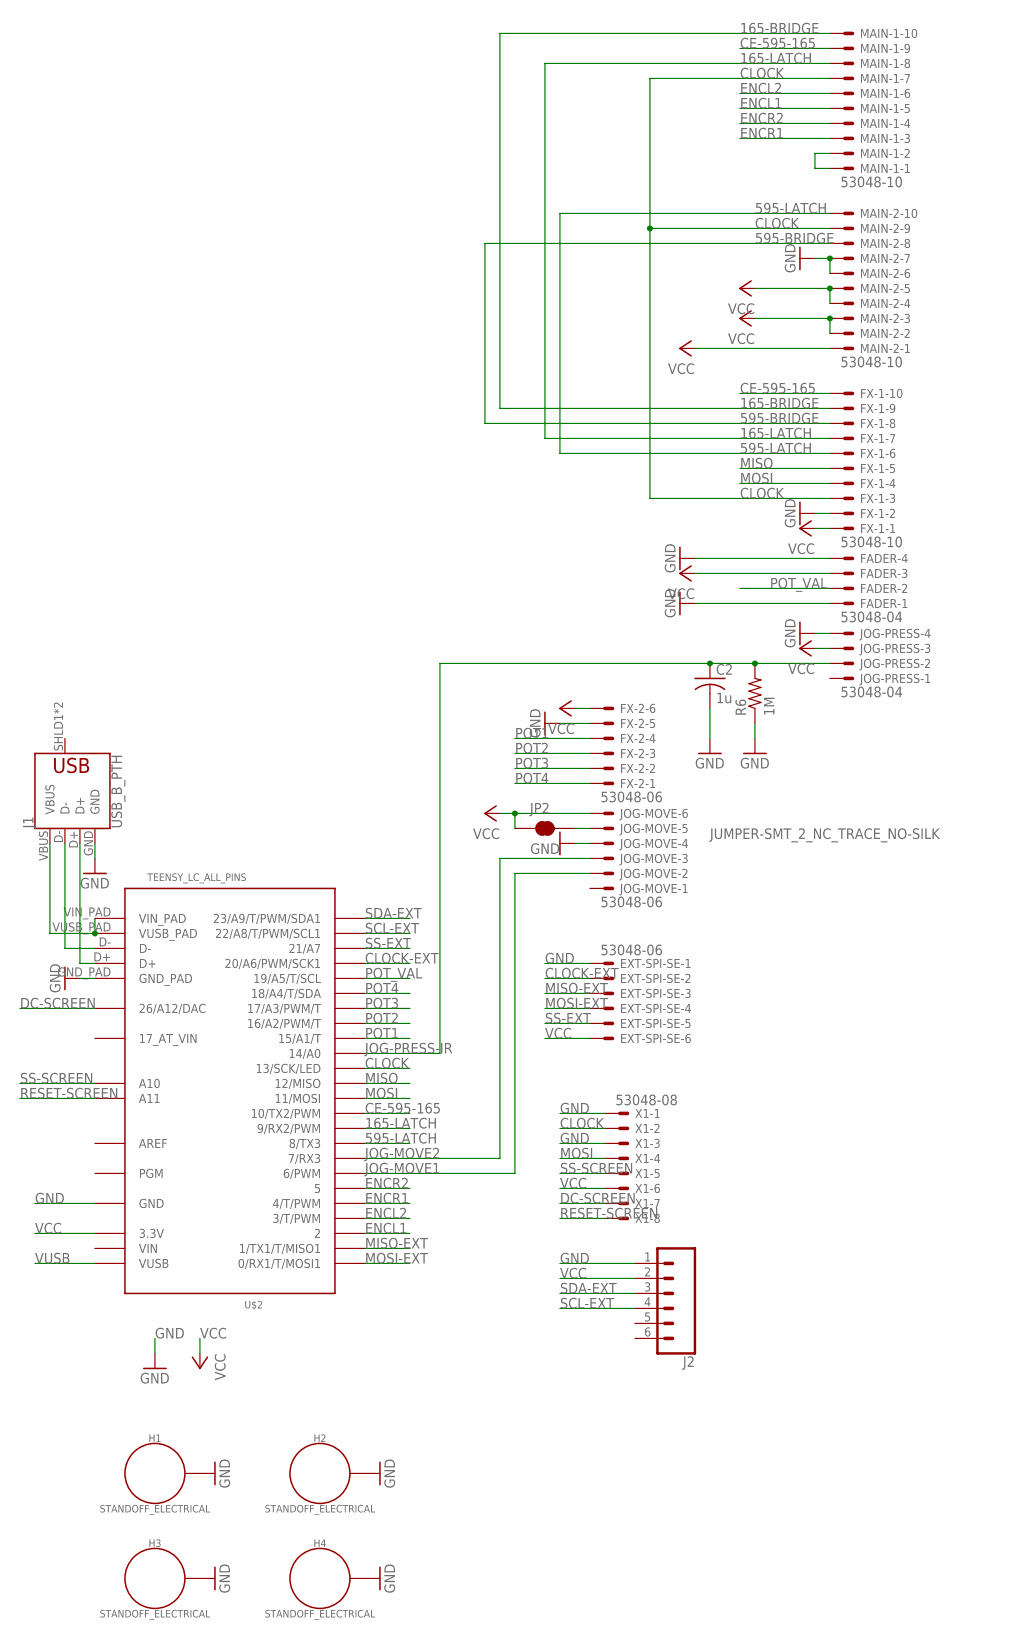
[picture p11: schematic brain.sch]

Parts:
C2: 1u; C1206
EXT-SPI-SE: 53048-06
FADER: 53048-04
FX-1: 53048-10
FX-2: 53048-06
H1, H2, H3, H4: STANDOFF_ELECTRICAL; STANDOFF-ELECTRICAL
J1: USB_B_PTH; USB-B-PTH
J2: CONN_06SILK_FEMALE_PTH; 1X06
JOG-MOVE: 53048-06
JOG-PRESS: 53048-04
JP2: JUMPER-SMT_2_NC_TRACE_NO-SILK; SMT-JUMPER_2_NC_TRACE_NO-SILK
MAIN-1, MAIN-2: 53048-10
R6: 1M; R1206
U$2: TEENSY_LC_ALL_PINS; TEENSY_3.0-3.2&LC_ALL_PINS
X1: 53048-08

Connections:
165-BRIDGE: FX-1.9, MAIN-1.10
165-LATCH: FX-1.7, MAIN-1.8, U$2.9 (9/RX2/PWM)
595-BRIDGE: FX-1.8, MAIN-2.8
595-LATCH: FX-1.6, MAIN-2.10, U$2.8 (8/TX3)
AREF: U$2.AREF
CE-595-165: FX-1.10, MAIN-1.9, U$2.10 (10/TX2/PWM)
CLOCK: FX-1.3, MAIN-1.7, MAIN-2.9, U$2.13 (13/SCK/LED), X1.2
CLOCK-EXT: EXT-SPI-SE.2, U$2.20/A6 (20/A6/PWM/SCK1)
DC-SCREEN: U$2.RESET/DAC (26/A12/DAC), X1.7
ENCL1: MAIN-1.5, U$2.2
ENCL2: MAIN-1.6, U$2.3 (3/T/PWM)
ENCR1: MAIN-1.3, U$2.4 (4/T/PWM)
ENCR2: MAIN-1.4, U$2.5
GND: C2.2, EXT-SPI-SE.1, FADER.1, FADER.4, FX-1.2, FX-2.5, H1.P1, H2.P1, H3.P1, H4.P1, J1.GND, J2.1, JOG-MOVE.4, JOG-PRESS.4, MAIN-2.6, MAIN-2.7, R6.1, U$2.AGND (GND), U$2.GND, U$2.GND1 (GND), U$2.GND_PAD, X1.1, X1.3
JOG-MOVE1: JOG-MOVE.2, U$2.6 (6/PWM)
JOG-MOVE2: JOG-MOVE.3, U$2.7 (7/RX3)
JOG-PRESS-IR: C2.1, JOG-PRESS.2, R6.2, U$2.14/A0
MISO: FX-1.5, U$2.12 (12/MISO)
MISO-EXT: EXT-SPI-SE.3, U$2.1 (1/TX1/T/MISO1)
MOSI: FX-1.4, U$2.11 (11/MOSI), X1.4
MOSI-EXT: EXT-SPI-SE.4, U$2.0 (0/RX1/T/MOSI1)
unnamed: JOG-MOVE.5, JP2.2
unnamed: MAIN-1.1, MAIN-1.2
unnamed: J1.VBUS, U$2.VIN_PAD, U$2.VUSB_PAD
unnamed: J1.D-, U$2.D-
unnamed: J1.D+, U$2.D+
POT1: FX-2.4, U$2.15/A1 (15/A1/T)
POT2: FX-2.3, U$2.16/A2 (16/A2/PWM/T)
POT3: FX-2.2, U$2.17/A3 (17/A3/PWM/T)
POT4: FX-2.1, U$2.18/A4 (18/A4/T/SDA)
POT_VAL: FADER.2, U$2.19/A5 (19/A5/T/SCL)
RESET-SCREEN: U$2.A11, X1.8
SCL-EXT: J2.4, U$2.22/A8 (22/A8/T/PWM/SCL1)
SDA-EXT: J2.3, U$2.23/A9 (23/A9/T/PWM/SDA1)
SS-EXT: EXT-SPI-SE.5, U$2.21/A7
SS-SCREEN: U$2.A10, X1.5
VCC: EXT-SPI-SE.6, FADER.3, FX-1.1, FX-2.6, J2.2, JOG-MOVE.6, JOG-PRESS.3, JP2.1, MAIN-2.1, MAIN-2.2, MAIN-2.3, MAIN-2.4, MAIN-2.5, U$2.3.3V, U$2.3.3V1 (3.3V), X1.6
VIN: U$2.VIN
VUSB: U$2.VUSB

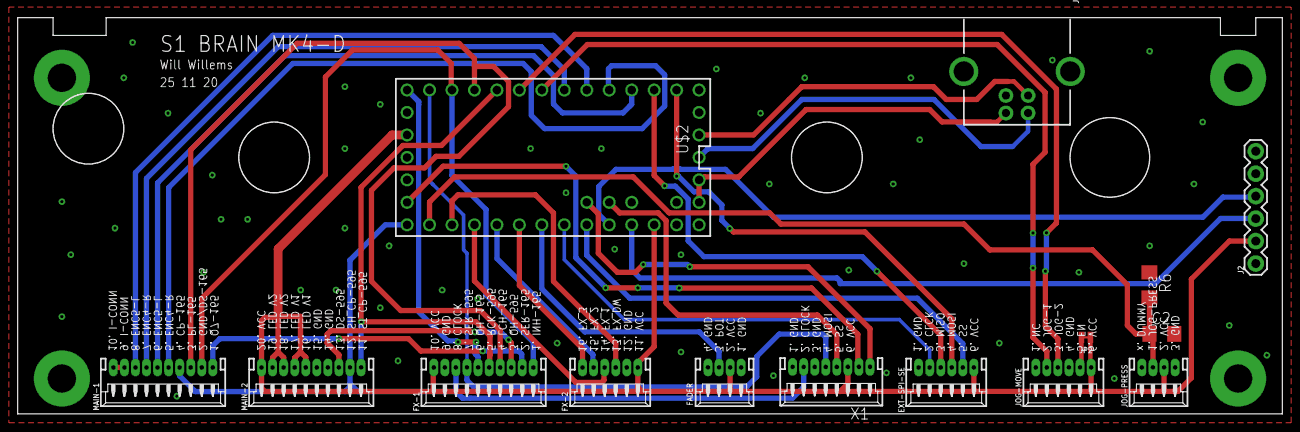
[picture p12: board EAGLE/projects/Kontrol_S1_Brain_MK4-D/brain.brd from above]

Board: 2 copper layers, 143.0 x 44.8 mm, 19 parts (0 on the bottom side), 36 nets.

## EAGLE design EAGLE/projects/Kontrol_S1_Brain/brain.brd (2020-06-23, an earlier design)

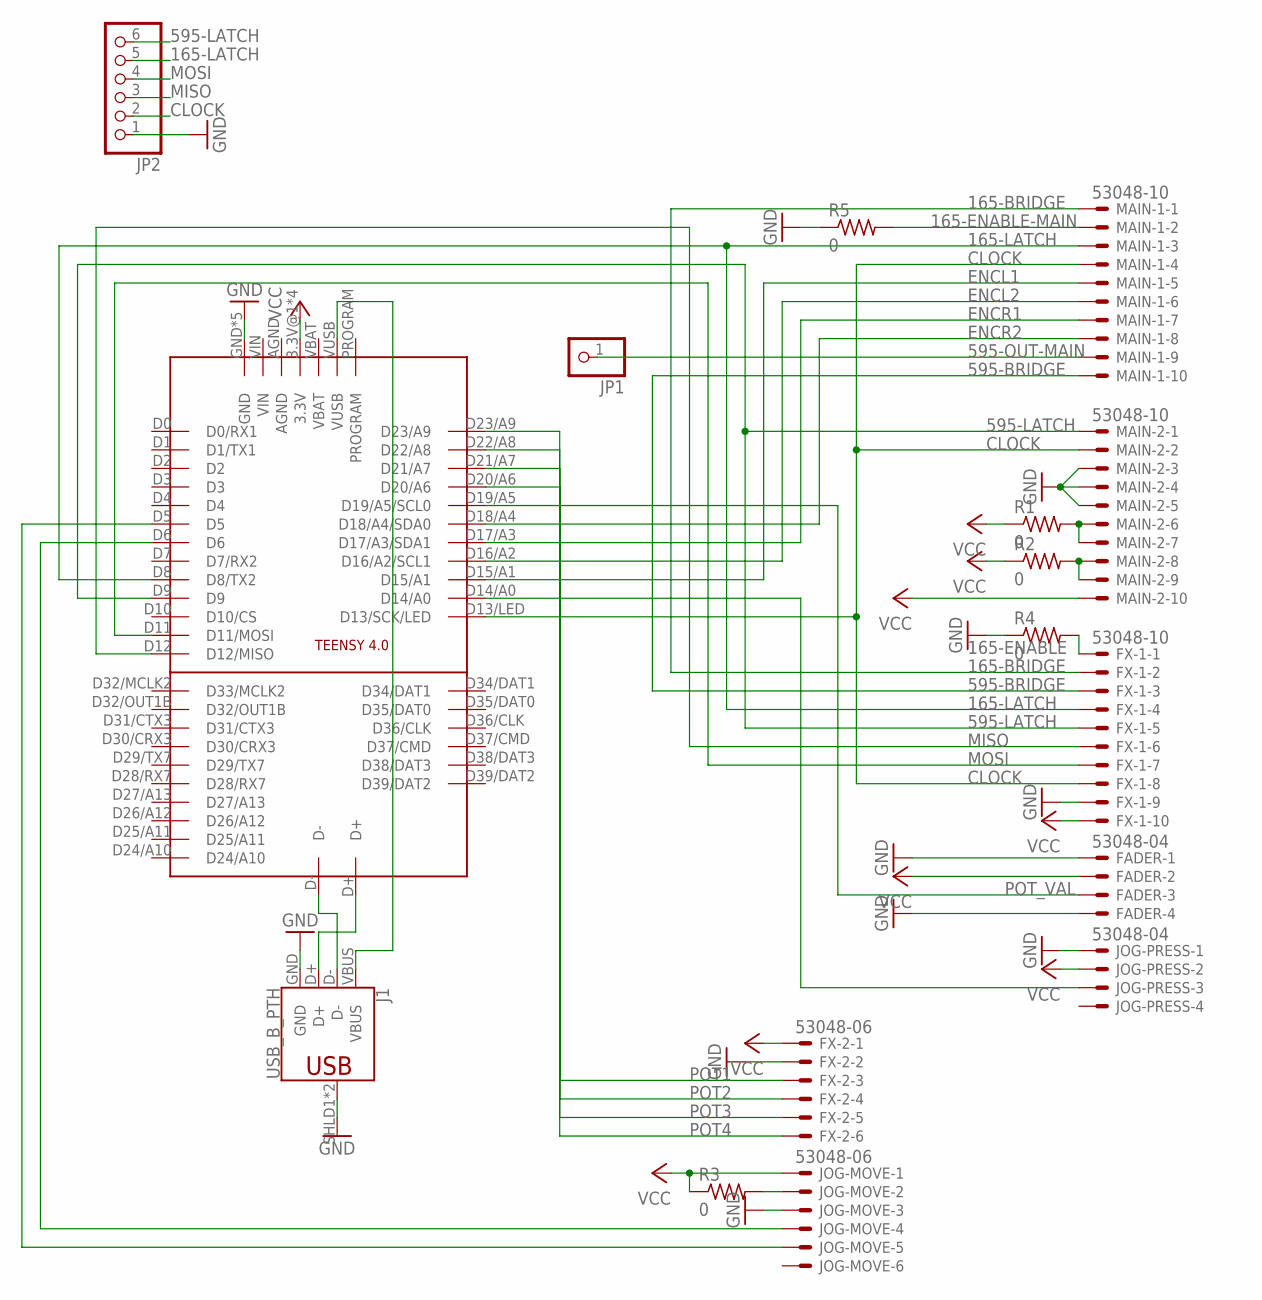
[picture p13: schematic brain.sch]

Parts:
FADER: 53048-04
FX-1: 53048-10
FX-2: 53048-06
J1: USB_B_PTH; USB-B-PTH
JOG-MOVE: 53048-06
JOG-PRESS: 53048-04
JP1: PINHD-1X1; 1X01
JP2: PINHD-1X6; 1X06
MAIN-1, MAIN-2: 53048-10
R1, R2, R3, R4, R5: 0; R1206
U$1: TEENSY-4.0-FULL-BRAKE-PADS

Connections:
165-BRIDGE: FX-1.2, MAIN-1.1
165-ENABLE: FX-1.1, R4.2
165-ENABLE-MAIN: MAIN-1.2, R5.2
165-LATCH: FX-1.4, JP2.5, MAIN-1.3, U$1.D8 (D8/TX2)
595-BRIDGE: FX-1.3, MAIN-1.10
595-LATCH: FX-1.5, JP2.6, MAIN-2.1, U$1.D9
595-OUT-MAIN: JP1.1, MAIN-1.9
CLOCK: FX-1.8, JP2.2, MAIN-1.4, MAIN-2.2, U$1.D13/LED (D13/SCK/LED)
ENCL1: MAIN-1.5, U$1.D15/A1
ENCL2: MAIN-1.6, U$1.D16/A2 (D16/A2/SCL1)
ENCR1: MAIN-1.7, U$1.D17/A3 (D17/A3/SDA1)
ENCR2: MAIN-1.8, U$1.D18/A4 (D18/A4/SDA0)
GND: FADER.1, FADER.4, FX-1.9, FX-2.2, J1.GND, J1.SHLD1 (SHIELD), J1.SHLD2 (SHIELD), JOG-MOVE.3, JOG-PRESS.1, JP2.1, MAIN-2.3, MAIN-2.4, MAIN-2.5, R4.1, R5.1, U$1.GND, U$1.GND@1 (GND), U$1.GND@2 (GND), U$1.P$11 (GND), U$1.P$12 (GND)
MISO: FX-1.6, JP2.3, U$1.D12 (D12/MISO)
MOSI: FX-1.7, JP2.4, U$1.D11 (D11/MOSI)
unnamed: MAIN-2.8, MAIN-2.9, R2.2
unnamed: MAIN-2.6, MAIN-2.7, R1.2
unnamed: JOG-PRESS.3, U$1.D14/A0
unnamed: JOG-MOVE.2, R3.2
unnamed: JOG-MOVE.4, U$1.D6
unnamed: JOG-MOVE.5, U$1.D5
unnamed: J1.D+, U$1.D+
unnamed: J1.D-, U$1.D-
unnamed: J1.VBUS, U$1.VUSB
POT1: FX-2.3, U$1.D20/A6
POT2: FX-2.4, U$1.D21/A7
POT3: FX-2.5, U$1.D22/A8
POT4: FX-2.6, U$1.D23/A9
POT_VAL: FADER.3, U$1.D19/A5 (D19/A5/SCL0)
VCC: FADER.2, FX-1.10, FX-2.1, JOG-MOVE.1, JOG-PRESS.2, MAIN-2.10, R1.1, R2.1, R3.1, U$1.3.3V@1 (3.3V), U$1.3.3V@2 (3.3V), U$1.3V3 (3.3V), U$1.ON/OFF (3.3V)

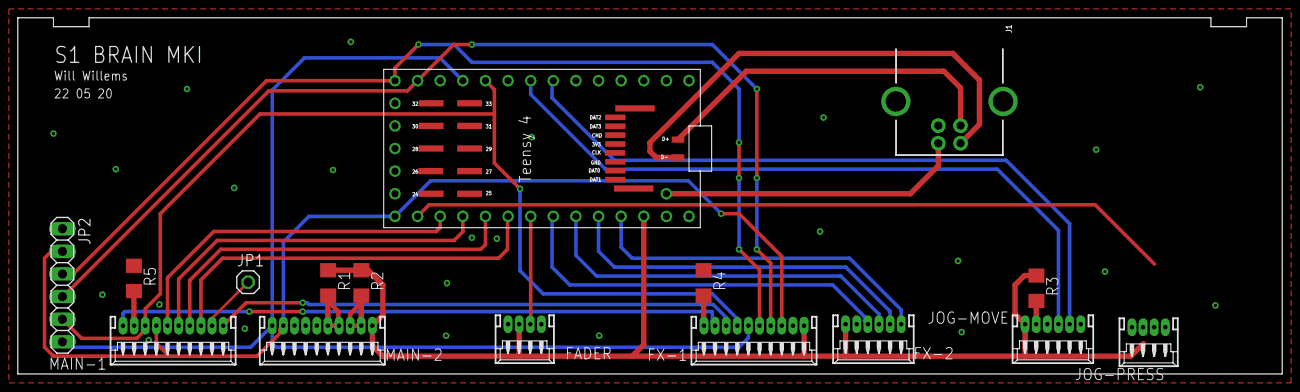
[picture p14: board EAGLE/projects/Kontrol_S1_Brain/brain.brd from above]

Board: 2 copper layers, 142.0 x 40.0 mm, 16 parts (0 on the bottom side), 30 nets.

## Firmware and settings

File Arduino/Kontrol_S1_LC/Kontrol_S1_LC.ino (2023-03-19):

#include <SPI.h>
#include <Encoder.h>

#include "unit_c.h"

#define debug 0

#define latchPinIn 9 // 74HC165
#define latchPinOut 8 // 74HC595
#define cePin 10 // 74HC165 & 74HC595

#define faderPin 19

#define touchPin 14

#define FX_PINS 15, 16, 17, 18
#define FX_PINS_CC 10, 11, 12, 13

// Channel number for MIDI messagess
const int channelNumber = 1;

// IC ammount for serial data
const int ica595 = 7;
const int ica165 = 4;

const byte ledsOffState[ica595] = { LEDS_SERIAL_OFF_STATE };
byte ledsState[ica595] = { LEDS_SERIAL_OFF_STATE };

const byte buttonsOffState[ica165] = { BUTTONS_SERIAL_OFF_STATE };
byte buttonsState[ica165] = { BUTTONS_SERIAL_OFF_STATE };

const byte digitStates[22] = {
  DIGIT_STATE_1_32,
  DIGIT_STATE_1_16,
  DIGIT_STATE_1_8,
  DIGIT_STATE_1_4,
  DIGIT_STATE_1_2,
  DIGIT_STATE_1,
  DIGIT_STATE_2,
  DIGIT_STATE_4,
  DIGIT_STATE_8,
  DIGIT_STATE_16,
  DIGIT_STATE_32
};

//const int ledMap[64] = {
//  1,
//  2,
//  3,
//  4,
//  5,6,7,8,9,
//  (4*8+4 - 1), // 9
//  11,
//  (4*8+5 - 1), // 11
//  13,
//  (4*8+6 - 1) // 13
//  , 15,
//  (4*8+7 - 1) // 15
//};

const int ledMap[64] = {
  (FX_CHIP_NR*8 + 0), // 0,
  (FX_CHIP_NR*8 + 1), // 1,
  (FX_CHIP_NR*8 + 2), // 2,
  (FX_CHIP_NR*8 + 3), // 3,
  (FX_CHIP_NR*8 + 4), // 4,
  6,7,8, // not used on FX chip
  
  (-1),  // 8
  (CUP_CHIP_NR*8 + 7), // 9 - SHIFT
  (-1), // 10
  (CUP_CHIP_NR*8 + 4), // 11 - SYNC
  (-1), // 12
  (CUP_CHIP_NR*8 + 5), // 13 - CUE
  (-1), // 13
  (CUP_CHIP_NR*8 + 6), // 15 - PLAY
  
  (26), // 16 - C
  (CUP_CHIP_NR*8 + 0), // 17 - S1
  (24), // 18 - LOOP IN
  (CUP_CHIP_NR*8 + 1), // 19 - S2
  (25), // 20 - LOOP OUT
  (CUP_CHIP_NR*8 + 2), // 21 - S3
  (27), // 22 - LOAD
  (CUP_CHIP_NR*8 + 3), // 23 - S4
  
  (LP_CHIP_NR*8 + 8 - 1), // 24
  (LP_CHIP_NR*8 + 8 - 2), // 25
  (LP_CHIP_NR*8 + 8 - 3), // 26
  (LP_CHIP_NR*8 + 8 - 4), // 27
  (LP_CHIP_NR*8 + 8 - 5), // 28
  (LP_CHIP_NR*8 + 8 - 6), // 29
  (LP_CHIP_NR*8 + 8 - 7), // 30
  (LP_CHIP_NR*8 + 8 - 8), // 31
};

const int buttonMap[32] = {
  0,
  1,
  2,
  3,
  4,
  5,
  6,
  7,

  (8 + 16), // OFFSRT UP NOY MAPPED
  (9 + 16), // OFFSET DOWN NOT MAPPED
  (10 + 16), // SET LOOP
  (11 + 16), // ACTIVE LOOP
  (12 + 16), // empty ??
  (13 + 16), // empty ??
  (14 + 16), // empty ??
  (15 + 16), // empty ??

  (16 + 0), // C
  (17 + 0), // S1
  (18 + 0), // LOOP IN
  (19 + 0), // S2
  (20 + 0), // LOOP OUT
  (21 + 0), // S3
  (22 + 0), // LOAD
  (23 + 0), // S4
  
  (24 - 16), // CUE1
  (25 - 16), // SHIFT
  (26 - 16), // CUE2
  (27 - 16), // SYNC
  (28 - 16), // CUE3
  (29 - 16), // CUE
  (30 - 16), // CUE4
  (31 - 16) // PLAY
};
// 13 CUE

//const int buttonMap[32] = {
//  0,
//  1,
//  2,
//  3,
//  4,
//  5,
//  6,
//  7,
//
//  8,
//  9,
//  10,
//  11,
//  12,
//  13,
//  14,
//  15,
//
//  16,
//  17,
//  18,
//  19,
//  20,
//  21,
//  22,
//  23,
//  
//  24,
//  25,
//  26,
//  27,
//  28,
//  29,
//  30,
//  31
//};

// LED OFF STATES from least significant bit (last one so notation is in reverse)
// -- BYTE [5]: 0b01010101 --
// CUE1 green - CUE1 blue - CUE2 green - CUE2 blue - CUE3 green - CUE3 blue - CUE4 green - CUE4 blue 
// -- BYTE [4]: 0b00000000 --
// Sample 1 - Sample 2 - Sample 3 - Sample 4 - SYNC - CUE - PLAY - SHIFT
// -- BYTE [3]: 0b11000000 --
// ON AIR - SAMPLES - DECK A/B - DECK C/D - KEYLOCK - MASTER - TEMPO OFFSET UP - TEMPO OFFSET DOWN
// -- BYTE [2]: 0b00000000 --
// LOOP IN - LOOP OUT - TOGGLE DECK C/D - LOAD - NONE - NONE - NONE -NONE
// -- BYTE [1]: 0b11111111 -- LEFT DIGIT 
// UP-MIDDLE - UP-RIGHT - DOT - UP-LEFT - DOWN-LEFT - DONW-MIDDLE - MIDDLE-MIDDLE - DOWN-RIGHT
// -- BYTE [0]: 0b11111111 -- RIGHT DIGIT
// DM - DL - UL - UM - UR - DR - MM - DOT

Encoder encoderLeft(2, 3);
Encoder encoderRight(4, 5);

Encoder encoderJog(6, 7);

const int fxPins[4] = {FX_PINS};
const int fxPinsCC[4] = {FX_PINS_CC};
int fxPinsState[4] = {64, 64, 64, 64};

int faderState = 0;

// depends on resistor value 
const int jogPressThresh = 980;
uint jogPressWindow = 0b00000000000000000000000000000000;
bool jogPressState = false;

void setup () {
  // setup SPI
  SPI.begin ();
  SPI.beginTransaction(SPISettings(8000000, MSBFIRST, SPI_MODE0));
  // set latch pins as output
  pinMode(latchPinIn, OUTPUT);
  pinMode(latchPinOut, OUTPUT);
  
  pinMode(cePin, OUTPUT);
  
  // set fader pin as input
  pinMode(faderPin, INPUT);
  // set jog touch as input
  pinMode(touchPin, INPUT);
  // set fx pins as input
  for(int i = 0; i < 4; i++) {
    pinMode(fxPins[i], INPUT);
  }
  // set latch pins to initial state
  digitalWrite (latchPinIn, HIGH);
  digitalWrite (latchPinOut, HIGH);
  digitalWrite (cePin, HIGH);
  // setup handlers for USB MIDI
  usbMIDI.setHandleNoteOn(handleNoteOn);
  usbMIDI.setHandleNoteOff(handleNoteOff);
  usbMIDI.setHandleControlChange(handleControlChange);
  // setup led state and start-up animation
  clearLedsState();
  
  for (int i = 0; i < (ica595*8); i++) {
    // flip bit at position
    setLedState(i, 1);
    sendLedsState();
    delay(20);
  }

  clearLedsState();
  setDigitState(8); // DEBUG
  sendLedsState();
}

void loop () {
  readButtonState();
  readEncoders();
  readTempoFader();
  readFXKnobs();
  readJogPress();
  // read USB MIDI
  usbMIDI.read();
}

void readButtonState () {
  byte newButtonsState[ica165];
  // pulse the parallel load latch
  digitalWrite (latchPinIn, LOW);
  delayMicroseconds(5); // doesn't break when we remove this
  digitalWrite (latchPinIn, HIGH);
  delayMicroseconds(5); // doesn't break when we remove this

  digitalWrite (cePin, LOW);
  
  // get new button state
  for (int i = 0; i < ica165; i++) {
    newButtonsState[i] = SPI.transfer(0b00000000);
  }

  digitalWrite (cePin, HIGH);
  
  // compare to previous button state and send midi messages
  for (int i = 0; i < (ica165 * 8); i++) {
    const int arrayEl = i/8;
    const int byteEl = i%8;
    const bool offState = bitRead(buttonsOffState[arrayEl], byteEl);
    const bool oldState = bitRead(buttonsState[arrayEl], byteEl);
    const bool newState = bitRead(newButtonsState[arrayEl], byteEl);
    if (newState != oldState) {
      if (newState ? !offState : offState) {
        usbMIDI.sendNoteOn(buttonMap[i], 127, channelNumber);
      } else {
        usbMIDI.sendNoteOff(buttonMap[i], 127, channelNumber);
      }
      
      if (debug) {
        Serial.print("Button nr: ");
        Serial.print(i);
        Serial.print(" Map: ");
        Serial.print(buttonMap[i]);
        Serial.print(" now: ");
        Serial.println(newState ? !offState : offState);
      }
    }
  }

  for (int i = 0; i < ica165; i++) {
    buttonsState[i] = newButtonsState[i];
  }
}

void sendLedsState () {
  // set latch pin 595 to fill registers with state
  delayMicroseconds(5);
  digitalWrite (latchPinOut, LOW);
  delayMicroseconds(5);
  // delay(1); // not needed, or can be mS, EDIT: needed for C unit
  // send state
  for (int i = 0; i < ica595; i++) {
    SPI.transfer(ledsState[i]);
  }
  Serial.println("\n");
  // load state into outputs
  digitalWrite (latchPinOut, HIGH);
}

void setLedState (int ledNumber, bool newState) {
  if (ledNumber < 0) {
    if (debug) { Serial.println("Led number < 0"); }
    return;
  }
  int arrayEl = ledNumber/8;
  int byteEl  = ledNumber%8;
  bool offState = bitRead(ledsOffState[arrayEl], byteEl);
  bitWrite(ledsState[arrayEl], byteEl, (newState ? !offState : offState));

  if (debug) {
    Serial.print("Led nr: ");
    Serial.print(ledNumber);
    Serial.print(" State: ");
    Serial.println(newState);
  }
}

void setDigitState (int newState) {
  byte leftDigit = digitStates[(newState * 2)];
  byte rightDigit = digitStates[(newState * 2) + 1];
  ledsState[LDG_CHIP_NR] = leftDigit;
  ledsState[RDG_CHIP_NR] = rightDigit;

  if (debug) {
    Serial.print("Left digit: ");
    Serial.print(leftDigit, BIN);
    Serial.print(" right digit: ");
    Serial.println(rightDigit, BIN);
  }
}

void clearLedsState () {
  memcpy(ledsState, ledsOffState, sizeof ledsState);
}

void readEncoders () {
  int encoderLeftPosition = (encoderLeft.read() / 4);
  if (encoderLeftPosition != 0) {
    Serial.print("Encoder left position: ");
    Serial.println(encoderLeftPosition);
    // send encoder midi note
    if (encoderLeftPosition > 0) { usbMIDI.sendControlChange(0, 63, channelNumber); }
    else { usbMIDI.sendControlChange(0, 65, channelNumber); }
    // reset enncoder
    encoderLeft.write(0);
  }
  // read and proccess right encoder
  int encoderRightPosition = (encoderRight.read() / 4);
  if (encoderRightPosition != 0) {
    Serial.print("Encoder right position: ");
    Serial.println(encoderRightPosition);
    // send encoder midi note
    if (encoderRightPosition > 0) { usbMIDI.sendControlChange(1, 63, channelNumber); }
    else { usbMIDI.sendControlChange(1, 65, channelNumber); }
    // reset enncoder
    encoderRight.write(0);
  }
  // read and proccess jog encoder
  int encoderJogPosition = (encoderJog.read() / 4); // only does -4 and 4
  if (encoderJogPosition != 0) {
    Serial.print("Encoder jog position: ");
    Serial.println(encoderJogPosition);
    // send encoder midi note55
    if (encoderJogPosition > 0) { usbMIDI.sendControlChange(2, 63, channelNumber); }
    else { usbMIDI.sendControlChange(2, 65, channelNumber); }
    // reset enncoder
    encoderJog.write(0);
  }
}

void readTempoFader () {
  int newFaderState = 127 - (analogRead(faderPin) / 8); // inverted
  if (newFaderState != faderState) {
    faderState = newFaderState;
    usbMIDI.sendControlChange(5, faderState, channelNumber);
  }
}

void readFXKnobs () {
  for (int i = 0; i < 4; i++) {
    int newKnobState = (analogRead(fxPins[i]) / 8);
    if (newKnobState != fxPinsState[i]) {
      fxPinsState[i] = newKnobState;
      usbMIDI.sendControlChange(fxPinsCC[i], fxPinsState[i], channelNumber);
    }
  }
}

void readJogPress () {
  int jogRead = analogRead(touchPin);
  jogPressWindow = jogPressWindow << 1; // shift bit
  bitWrite(jogPressWindow, 0, jogRead <= jogPressThresh); // write bit

  Serial.print(jogRead);
  Serial.print("\t");
  Serial.println((jogRead <= jogPressThresh) ? 100 : 0);

  if (jogPressState == HIGH && jogPressWindow == 0b00000000000000000000000000000000) {
    jogPressState = LOW;
    usbMIDI.sendControlChange(55, jogPressState ? 127 : 0, channelNumber);
  } else if (jogPressState == LOW && jogPressWindow == 0b11111111111111111111111111111111){
    jogPressState = HIGH;
    usbMIDI.sendControlChange(55, jogPressState ? 127 : 0, channelNumber);
  }
}

void handleNoteOn(byte channel, byte note, byte velocity) {
  if (channel != channelNumber) { return; } 
  int led = getNoteLed(note, velocity, true);
  setLedState(led, 1);
  sendLedsState();
  if (debug) {
    Serial.print("Note On, ch=");
    Serial.print(channel, DEC);
    Serial.print(", note=");
    Serial.print(note, DEC);
    Serial.print(", led=");
    Serial.print(led, DEC);
    Serial.print(", velocity=");
    Serial.println(velocity, DEC);
  }
}

void handleNoteOff(byte channel, byte note, byte velocity) {
  if (channel != channelNumber) { return; }
  int led = getNoteLed(note, velocity, false);
  setLedState(led, 0);
  sendLedsState();
  if (debug) {
    Serial.print("Note Off, ch=");
    Serial.print(channel, DEC);
    Serial.print(", note=");
    Serial.print(note, DEC);
    Serial.print(", velocity=");
    Serial.println(velocity, DEC);
  }
}

void handleControlChange(byte channel, byte control, byte value) {
  if (channel != channelNumber) { return; }
  if (control == 0) { 
    setDigitState(value);
    sendLedsState(); 
  }
  if (debug) {
    Serial.print("Control Change, ch=");
    Serial.print(channel, DEC);
    Serial.print(", control=");
    Serial.print(control, DEC);
    Serial.print(", value=");
    Serial.println(value, DEC);
  }
}

int getNoteLed(int note, int velocity, bool on) {
  if (note == 8 || note == 10 || note == 12 || note == 14) {
    Serial.print("CUE");
    Serial.print(note - 8);
    Serial.println(" ");
    // Serial.print((velocity == 6) ? 0 : 1);
    if (true) {
      // Loop
      if      (velocity == 6) {
        setLedState((CUE_CHIP_NR*8) + (note - 8) + 0, 1);
        setLedState((CUE_CHIP_NR*8) + (note - 8) + 1, 0);
      }
      // Load 
      else if (velocity == 4) { 
        setLedState((CUE_CHIP_NR*8) + (note - 8) + 0, 1); 
        setLedState((CUE_CHIP_NR*8) + (note - 8) + 1, 1); 
      }
      else if (velocity == 0) {
        setLedState((CUE_CHIP_NR*8) + (note - 8) + 0, 0);
        setLedState((CUE_CHIP_NR*8) + (note - 8) + 1, 0);
      }
      // Cue or anything else
      else {
        setLedState((CUE_CHIP_NR*8) + (note - 8) + 0, 0);
        setLedState((CUE_CHIP_NR*8) + (note - 8) + 1, 1);
      }
    }
    sendLedsState();
    return -1;
  }
  return ledMap[note];
}

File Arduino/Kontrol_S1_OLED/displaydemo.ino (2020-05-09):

#define TRACK_TITLE 0
#define TRACK_ARTIST 1
#define TRACK_BPM 2
#define TRACK_TIME 3
#define TRACK_PROGRESS 4

#include <Arduino.h>
#include <U8g2lib.h>

#ifdef U8X8_HAVE_HW_SPI
#include <SPI.h>
#endif
#ifdef U8X8_HAVE_HW_I2C
#include <Wire.h>
#endif

U8G2_SH1122_256X64_F_4W_HW_SPI u8g2(U8G2_R0, /* cs=*/ 10, /* dc=*/ 9, /* reset=*/ 8);				// Enable U8G2_16BIT in u8g2.h

const int screenWidth = 256;
const int screenHeight = 64;


const int barHeight = 3; // px

char trackTimeLeft[6] = {'0', '0', ':', '0', '0', '\0'};
int trackLength = 100;
int trackProgress = 0;

void setup(void) {
  Serial.begin(9600);
  u8g2.begin();

  setTrackName("There is A", false);
  setArtistName("Mall Grab", false);
  setTrackTime("06:45", false);
  setTempoValue("128.00", false);
 
  drawBarBox();
  u8g2.sendBuffer();
}

void loop(void) {

}

void serialEvent() {
  while (Serial.available()) {
    byte type = Serial.read();
    Serial.print("type: ");
    Serial.println(type);
    byte infoLength = Serial.read();
    Serial.print("infoLength: ");
    Serial.println(infoLength);

    
    char info[50]; // make this dynamic
    for (int i = 0; i <= infoLength; i++) {
    // Serial.println(Serial.available());
    // for (int i = 0; Serial.available() > 0; i++) {
      info[i] = (char)Serial.read();
      Serial.print(info[i]);
    }
    Serial.println("");
    if (type == TRACK_TITLE) {
      setTrackName(info, true);
    } else if (type == TRACK_ARTIST) {
      setArtistName(info, true);
    } else if (type == TRACK_BPM) {
      // tempo info is a string
      setTempoValue(info, true);
    } else if (type == TRACK_PROGRESS) {
      trackProgress = atoi(info);
      setBarWidth((260 * trackProgress) / trackLength);
      generateTimeLeftString(trackLength - trackProgress);
    } else if (type == TRACK_TIME) {
      trackLength = atoi(info);
      setBarWidth(((screenWidth - 4) * trackProgress) / trackLength);
//  } else if (type == ) {
    } else {
      Serial.println("Invalid type");
    }
  }
}

void setTrackName (char *name, bool update) { // todo make update optional
  // clear area by drawing black box
  u8g2.setDrawColor(0);
  u8g2.drawBox(0, (2*8), ((32-8)*8), (2*8));
  u8g2.setDrawColor(1);
  
  u8g2.setFont(u8g2_font_unifont_tf);  // choose a suitable font
  u8g2.drawStr(0,32, name);  // write something to the internal memoryv
  u8g2.sendBuffer();
  // if (update) { u8g2.updateDisplayArea(0, 2, (32-8), 3); }; // update relevant display section
}

void setArtistName (char *name, bool update) {
  // clear area by drawing black box
  u8g2.setDrawColor(0);
  u8g2.drawBox(0, 0, ((32-8)*8), (2*8));
  u8g2.setDrawColor(1);
  
  u8g2.setFont(u8g2_font_helvB14_tf);  // choose a suitable font
  u8g2.drawStr(0,14, name); // write something to the internal memory
  u8g2.sendBuffer();
  // if (update) { u8g2.updateDisplayArea(0, 0, (32-8), 2); }; // update relevant display section
}

void setTempoValue (char *tempo, bool update) {
  // clear area by drawing black box
  u8g2.setDrawColor(0);
  u8g2.drawBox(((32-8)*8), 0, (8*8), (2*8));
  u8g2.setDrawColor(1);
  
  u8g2.setFont(u8g2_font_helvB12_te); // u8g2_font_7x13B_mn, u8g2_font_profont17_mn
  u8g2.drawRBox(252-52, 0, 52, 17, 2);
  u8g2.setDrawColor(0);
  u8g2.drawStr(screenWidth - 2 - 52, 14, tempo);
  u8g2.setDrawColor(1);
  if (update) { u8g2.updateDisplayArea(32-8, 0, 8, 2); } //updateDisplayArea(32-4, 0, 4, 2); };
}

void setTrackTime (char *time, bool update) {
  // clear area by drawing black box
  u8g2.setDrawColor(0);
  u8g2.drawBox(((32-8)*8), (2*8), (8*8), (3*8));
  u8g2.setDrawColor(1);
  
  u8g2.setFont(u8g2_font_unifont_tf);
  u8g2.drawStr(screenWidth - 2 - 42, (14 + 18), time);
  if (update) { u8g2.updateDisplayArea(32-8, 2, 8, 3); };
}

void drawBarBox () {
  u8g2.drawBox(0,   (60-barHeight), 256,  1); // top
  u8g2.drawBox(0,   (64-1),         256,  1); // bottom
  u8g2.drawBox(0,   (60-barHeight), 1,    (4+barHeight)); // left
  u8g2.drawBox(255, (60-barHeight), 1,    (4+barHeight)); // right
}

void setBarWidth (int width) {
  // if == less than previous
  if (true) {
    u8g2.setDrawColor(0);
    u8g2.drawBox(2, (62-barHeight), (screenWidth - 4), barHeight);
    u8g2.setDrawColor(1);
  }
  u8g2.drawBox(2, (62-barHeight), width, barHeight);
  u8g2.sendBuffer();
  // u8g2.updateDisplayArea(0, 5, 32, 3);
}

void generateTimeLeftString (int seconds) {
  const int _minutes = seconds / 60;
  const int _seconds = seconds % 60;
  trackTimeLeft[0] = '0' + _minutes / 10;
  trackTimeLeft[1] = '0' + _minutes % 10;
  trackTimeLeft[2] = ':';
  trackTimeLeft[3] = '0' + _seconds / 10;
  trackTimeLeft[4] = '0' + _seconds % 10;
  trackTimeLeft[5] = '\0';
  Serial.println(trackTimeLeft);
  setTrackTime(trackTimeLeft, true);
}

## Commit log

2020-01-24 working encoders, leds and display
2020-01-27 Add comments, write untested 165 read, fix vars
    - Add some comments to clarify functionality.
    - Fix some var names.
    - Add logging of 74HC165 input states on LED read, does not work yet.
    [KontrolS1.ino]
2020-01-28 Create README
    Add chip info, pinout and default LED state.
2020-01-30 add working button reading
2020-01-30 Add jog pinouts, button packages/mapping & observations
2020-02-12 Add info about MK2 PCB
2020-02-12 add info about MK3 PCB
2020-05-12 Add info about right DS pin to pinout
2020-05-12 Add pic from other PCB
2020-05-13 Change SPI speed, add jog & fader support
2020-05-13 Fix 165's not working
    [KontrolS1.ino]
2020-05-16 Add early CAD files
    [potboard.brd, potboard.sch]
2020-05-16 Add custom PCB pinout
2020-05-17 Add general description of FX PCB and about pinout
2020-05-25 Add MK1 gerbers of boards to repo
2020-06-18 Add FX board integration, invert tempo & right encoder, fix 1 typo
    [KontrolS1.ino]
2020-06-18 Add gerbers second revision FX board
2020-06-23 clean up project structure
    [brain.brd, brain.sch, potboard.brd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]
2020-06-23 add info about 4 pin jog touch connector
2020-09-22 add new gen board designs
    [brain.brd, brain.sch, potboard.brd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]
2020-10-03 Add OLED PCB connections
2020-10-04 Add custom OLED board
    [OLED adapter.kicad_pcb, OLED adapter.sch]
2020-10-07 add note about 595 serial flow extra pin
2020-10-19 Add draft of MK3 board
    [brain.brd, brain.sch]
2020-10-19 extend ledmap for sample and range buttons
2020-10-25 D unit working, add buttonmap, multideck structure
2020-11-02 Add correct OLED driver pinout
2020-11-25 Add MK4 designs
    [brain.brd, brain.sch]
2020-11-25 add FX board MK4
    [potboard.brd, potboard.sch]
2020-12-09 Add simple BOM's
2020-12-09 add standoff length
2021-09-20 add screws to BOM
2021-10-27 update screw length
2021-10-27 update silkscreen
    [potboard.brd, potboard.sch]
2023-03-18 add 3d files for body smoothing
    [midiplug.stl, s4 front plug.stl, s4plugback84-130.stl]
2023-03-18 start eagle conversion to KiCAD
    [brain.kicad_pcb, brain.kicad_sch]
2023-06-25 add info photo sensor
2023-07-04 add nect-gen KiCAD files
    [Kontrol_S4_MK5.kicad_pcb, Kontrol_S4_MK5.kicad_sch, brain.kicad_pcb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]
2023-07-09 add jog press schematic
    [Kontrol S1 Jog Press.kicad_sch]

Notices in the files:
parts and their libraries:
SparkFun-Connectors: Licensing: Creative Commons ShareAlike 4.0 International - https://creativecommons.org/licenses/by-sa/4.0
